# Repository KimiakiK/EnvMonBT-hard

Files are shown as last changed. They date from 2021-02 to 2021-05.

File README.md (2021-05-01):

# EnvMonBT
[Software](https://github.com/KimiakiK/EnvMonBT-soft)

# Features
- 温度湿度気圧CO2計
- 直近1時間と24時間のグラフ表示
- 統計表示(平均、最大、最小)
- BLE接続

# Major Components  
- STM32F303K8
- 温湿度・気圧センサ BME280
- CO2センサ MH-Z19
- TFT 1.3インチ 240x240ドット
- Bluetooth RN4020

# Photos
EnvMonBT
EnvMonBT_BLE
EnvMonBT_EnvData

## PCB
- V2.1
PCB V2.1
- V2.0
PCB V2.0
- V1.0
PCB V1.0
PCB USB V1.0

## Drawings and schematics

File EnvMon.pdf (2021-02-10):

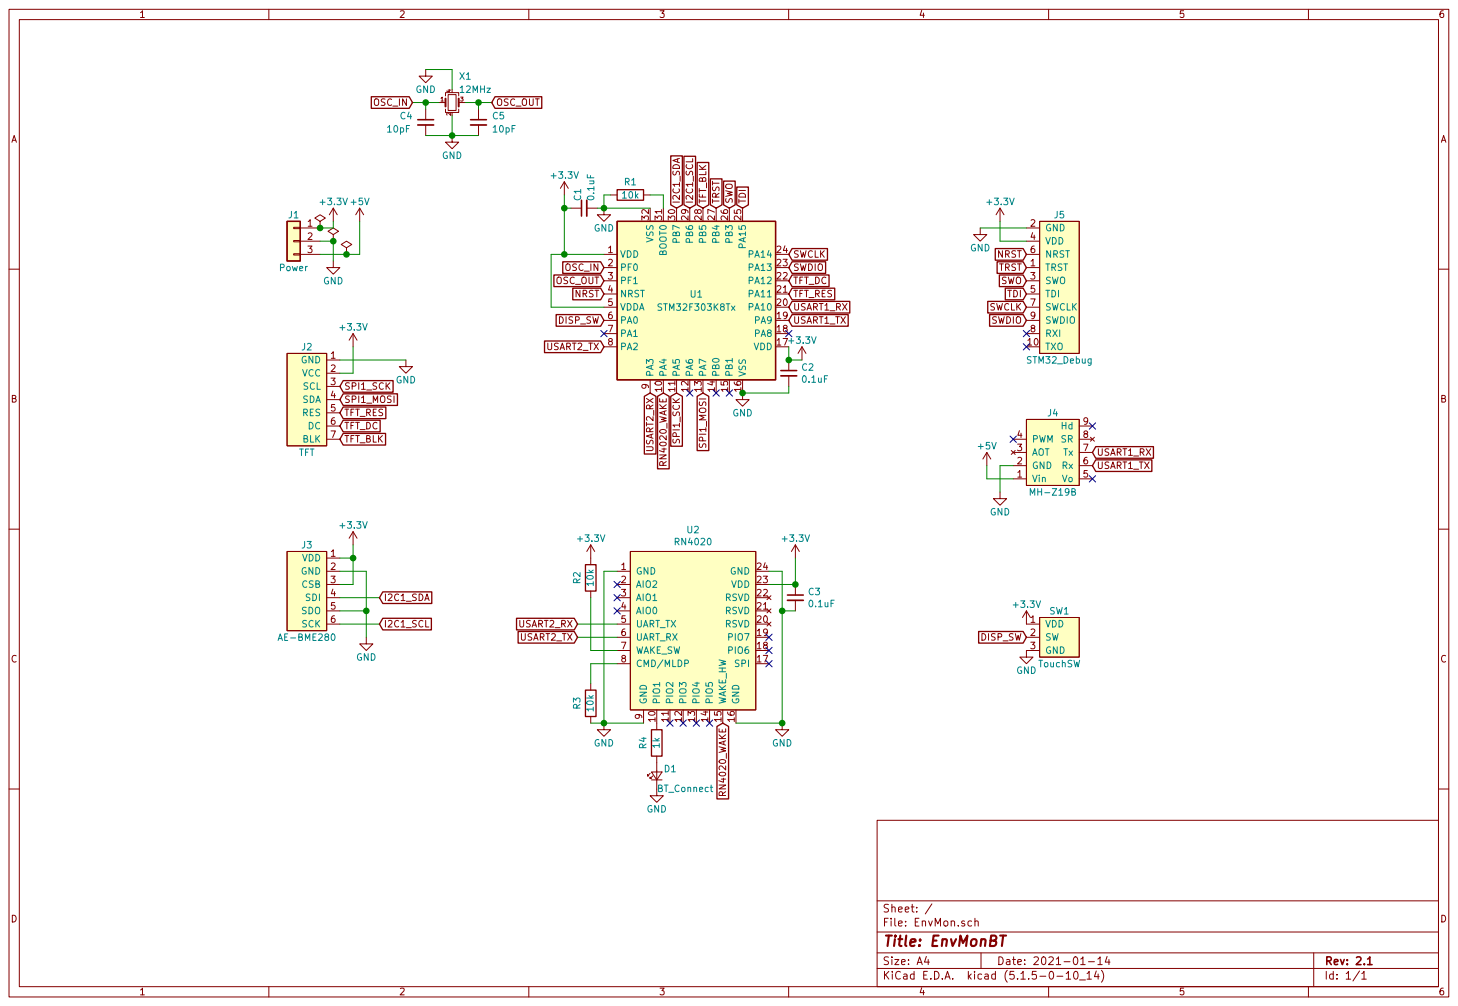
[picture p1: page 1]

File: EnvMon.sch Sheet: /
Id: 1/1 Title: EnvMonBT

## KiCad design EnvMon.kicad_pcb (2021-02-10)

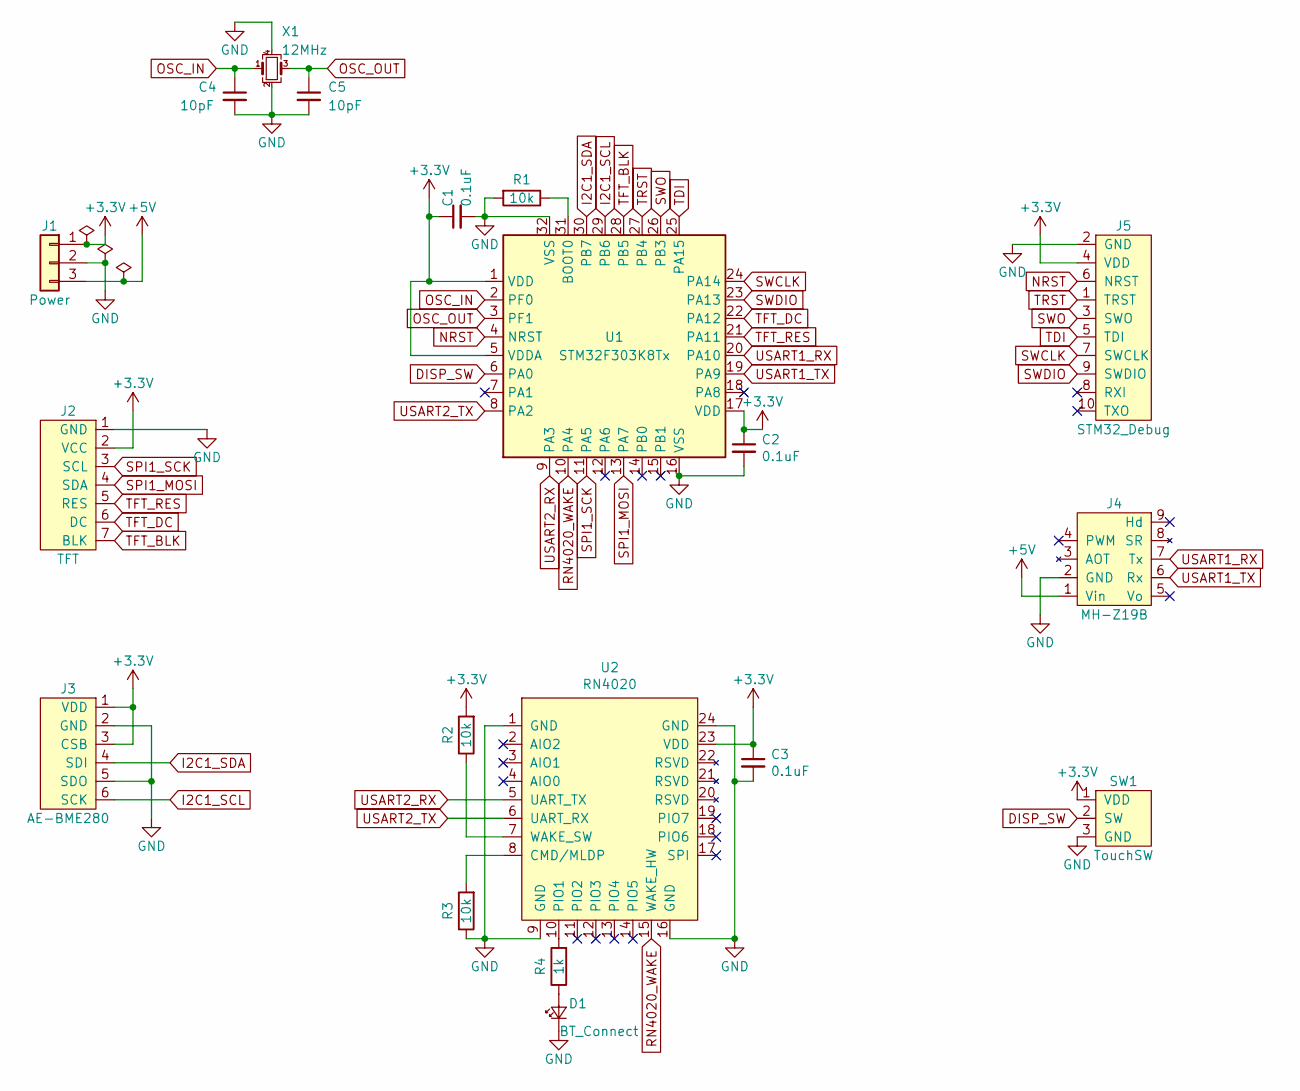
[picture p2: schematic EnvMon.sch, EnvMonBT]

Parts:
C1, C2, C3: 0.1uF; C_0603_1608Metric_Pad1.05x0.95mm_HandSolder
C4, C5: 10pF; C_0402_1005Metric
D1: BT_Connect; LED_0603_1608Metric_Pad1.05x0.95mm_HandSolder
J1: Power; USB_Power_Pin
J2: TFT; TFT_1.3_IPA
J3: AE-BME280; PinSocket_1x06_P2.54mm_Vertical
J4: MH-Z19B
J5: STM32_Debug; PinHeader_2x05_P1.27mm_Vertical
R1, R2, R3: 10k; R_0603_1608Metric_Pad1.05x0.95mm_HandSolder
R4: 1k; R_0603_1608Metric_Pad1.05x0.95mm_HandSolder
SW1: TouchSW
U1: STM32F303K8Tx; LQFP-32_7x7mm_P0.8mm_FusionPCB
U2: RN4020
X1: 12MHz; Crystal_SMD_3225-4Pin_3.2x2.5mm_HandSoldering

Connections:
+3V3: C1.1, C2.1, C3.1, J1.1, J2.2 (VCC), J3.1 (VDD), J3.3 (CSB), J5.4 (VDD), R2.2, SW1.1 (VDD), U1.1 (VDD), U1.5 (VDDA), U1.17 (VDD), U2.23 (VDD)
+5V: J1.3, J4.1 (Vin)
DISP_SW: SW1.2 (SW), U1.6 (PA0)
GND: C1.2, C2.2, C3.2, C4.2, C5.2, D1.1 (K), J1.2, J2.1 (GND), J3.2 (GND), J3.5 (SDO), J4.2 (GND), J5.2 (GND), R1.2, R3.1, SW1.3 (GND), U1.16 (VSS), U1.32 (VSS), U2.1 (GND), U2.9 (GND), U2.16 (GND), U2.24 (GND), X1.2, X1.4
I2C1_SCL: J3.6 (SCK), U1.29 (PB6)
I2C1_SDA: J3.4 (SDI), U1.30 (PB7)
NRST: J5.6 (NRST), U1.4 (NRST)
unnamed: D1.2 (A), R4.1
unnamed: R1.1, U1.31 (BOOT0)
unnamed: R2.1, U2.7 (WAKE_SW)
unnamed: R3.2, U2.8 (CMD/MLDP)
unnamed: R4.2, U2.10 (PIO1)
OSC_IN: C4.1, U1.2 (PF0), X1.1
OSC_OUT: C5.1, U1.3 (PF1), X1.3
RN4020_WAKE: U1.10 (PA4), U2.15 (WAKE_HW)
SPI1_MOSI: J2.4 (SDA), U1.13 (PA7)
SPI1_SCK: J2.3 (SCL), U1.11 (PA5)
SWCLK: J5.7 (SWCLK), U1.24 (PA14)
SWDIO: J5.9 (SWDIO), U1.23 (PA13)
SWO: J5.3 (SWO), U1.26 (PB3)
TDI: J5.5 (TDI), U1.25 (PA15)
TFT_BLK: J2.7 (BLK), U1.28 (PB5)
TFT_DC: J2.6 (DC), U1.22 (PA12)
TFT_RES: J2.5 (RES), U1.21 (PA11)
TRST: J5.1 (TRST), U1.27 (PB4)
USART1_RX: J4.7 (Tx), U1.20 (PA10)
USART1_TX: J4.6 (Rx), U1.19 (PA9)
USART2_RX: U1.9 (PA3), U2.5 (UART_TX)
USART2_TX: U1.8 (PA2), U2.6 (UART_RX)

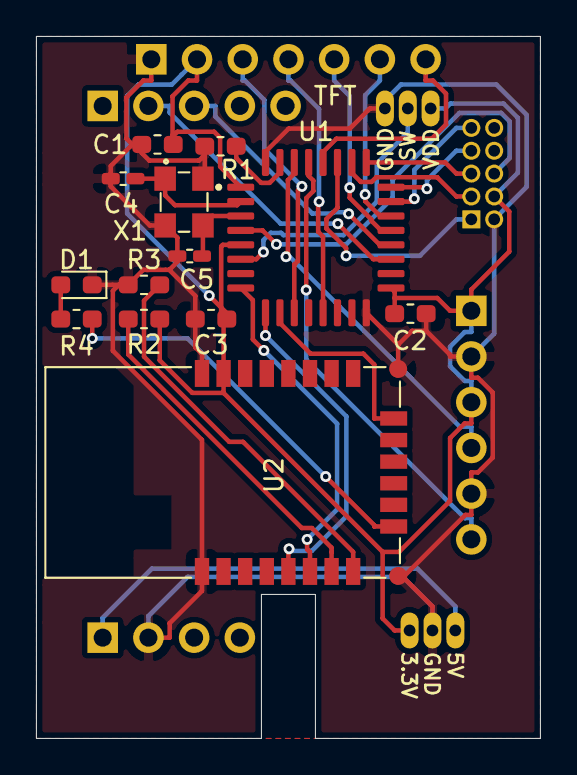
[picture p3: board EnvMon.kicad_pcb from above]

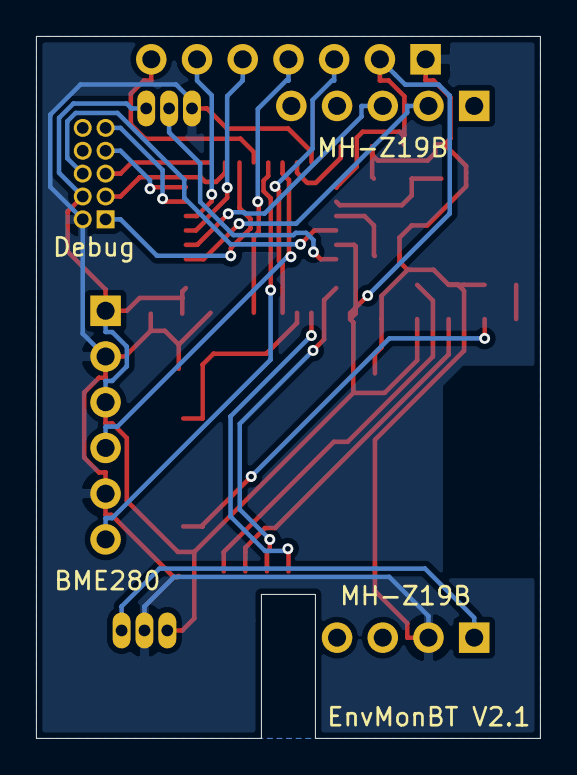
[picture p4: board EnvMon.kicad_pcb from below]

Board: 2 copper layers, 28.0 x 39.0 mm, 19 parts (3 on the bottom side), 29 nets.

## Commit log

2021-02-10 基板 V1.0
    [EnvMon-B_Cu.gbl, EnvMon-B_Mask.gbs, EnvMon-B_Paste.gbp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]
2021-02-10 基板 V2.0
    [EnvMon-B_Cu.gbl, EnvMon-B_Mask.gbs, EnvMon-B_Paste.gbp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]
2021-02-10 基板 V2.1
    [EnvMon-B_Cu.gbl, EnvMon-B_Mask.gbs, EnvMon-B_Paste.gbp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]
